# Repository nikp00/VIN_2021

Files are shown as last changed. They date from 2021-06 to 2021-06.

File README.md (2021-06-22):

# Končni projekt pri predmetu VIN 2020/21

Avtor: Nik Prinčič

Mentor: viš. pred. dr. Robert Rozman

### Kazalo

-   [Ideja delovanja](#ideja-delovanja)
-   [Razvojno okolje](#razvojno-okolje)
-   [Delovanje MPU6050](#delovanje-mpu6050)
-   [Delovanje Flex senzorja](#delovanje-flex-senzorja)
-   [Delovanje OLED zaslona (SSD1306)](#delovanje-oled-zaslona--ssd1306-)
-   [Generiranje PPM/CPPM signala](#generiranje-ppm-cppm-signala)
-   [Vezalna shema](#vezalna-shema)
-   [Problemi na katere sem naletel](#problemi-na-katere-sem-naletel)
-   [Zaključek](#zaklju-ek)

## Ideja delovanja

Nadziranje FPV drona z nagibanjem roke (roll, pitch, yaw) ter stiskanjem pesti (throttle). Za zaznavanje nagiba roke sem uporabil MPU6050 (6 DoF IMU), ki ima vgrajen DMP (digital motion processing) enoto, ki prepreči, da bi vrednosti, ki ju izmerita pospeškomer in žiroskop skozi čas začele odstopati zaradi pojava imenovanega "sensor drift". Za nadzor plina (throttle) pa sem uporabil flex senzor v kombinaciji z delilnikom napetosti. Flex senzor v delilniku napetosti opravlja nalogo variabilnega upora R1 (razpon upornosti od 30K do 110K), za upor R2 pa sem izbral upornost 68K. Za vizualizacijo pozicije vsakega od 4 kanalov (stick position) pa sem uporabil OLED zaslon. Vse skupaj pa nadzira Arduino Nano, ki tudi generira CPPM signal ki ga potem preko 3,5mm konektorja pošilja v oddajnik, ki komunicira z dronom.

Da bi vse navedene komponete lahko montiral na roko sem s pomočjo programa za 3D modeliranje in 3D tiskalnika izdelal nekaj nosilcev. Vsi nosilci so izdelani z delno fleksibilnega materiala TPU, da sel lažje prilagodijo obliki roke. Za napajanje pa sem uporabil 18650 Li-Ion celico, ki je preko BMS modula povezana na DC-DC boost module, ki napetost dvigne na 5V.

<p align="center">
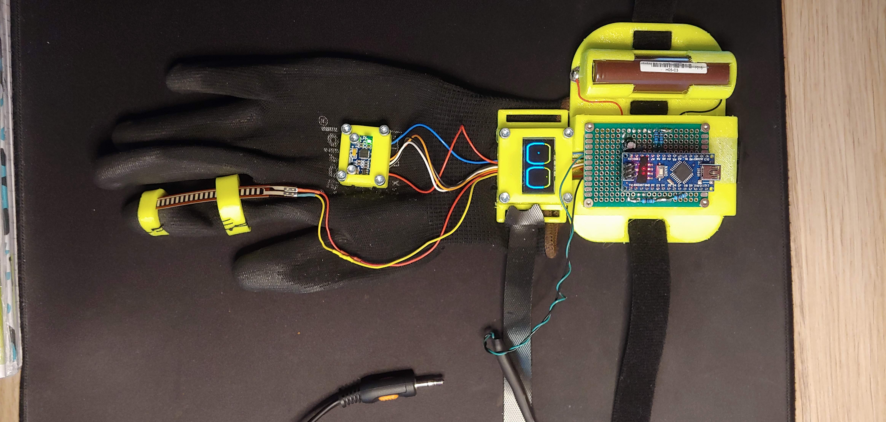
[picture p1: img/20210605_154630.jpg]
 
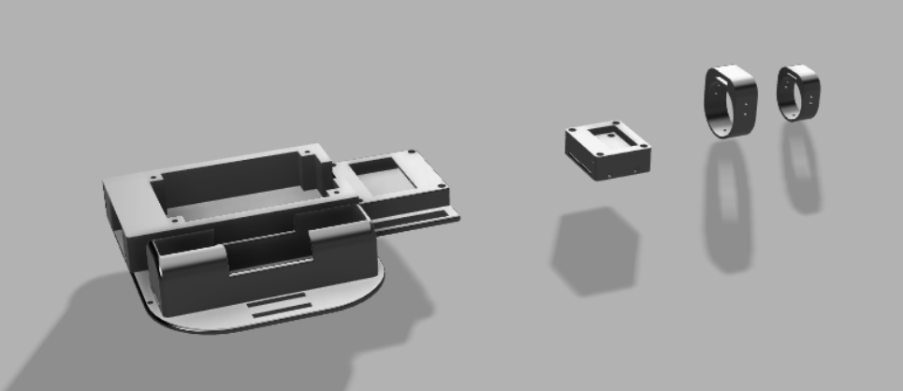
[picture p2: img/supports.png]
  
</p>

## Razvojno okolje

Za razvojno okolje sem si izbral [Platform IO](https://platformio.org/), ki deluje kot vtičnik (plugin) za Microsoft VS Code in ponuja precej več funkcionalnosti od klasičnega Arduino IDE okolja.

<p align="center">
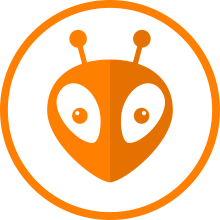
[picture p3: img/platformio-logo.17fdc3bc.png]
 
</p>

## Delovanje MPU6050

MPU6050 uporabljam v načinu, ki izkorišča DMP enoto, zato je poleg I2C povezave potrebna še povezava na prekinitveno nožico Arduina. Ko DMP enota sprocesira pordatke sproži prekinitev, ki Arduino opozori da so podatki pripravljeni za branje. Za interkcijo z MPU6050 sem uporabil knjižnico [Simple_MPU6050](https://github.com/ZHomeSlice/Simple_MPU6050), ki v DMP enoto naloži potrben program (Invensense Embedded MotionDriver 6.12) in olajša vso ostalo konfiguracijo in komunikacijo.

<p align="center">
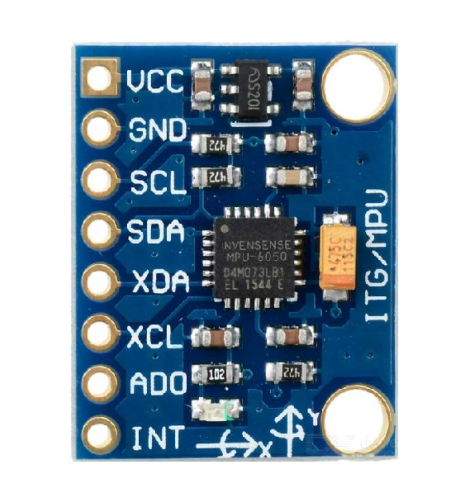
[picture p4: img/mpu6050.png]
 
</p>

## Delovanje Flex senzorja

Flex senzor je preko delilnika napetosti povezan na analogno nožico Arduina. Flex senzor v delilniku napetosti opravlja vlogo variabilnega upora R1, vrednost fiksnega upora R2 pa sem izbral tako, da delilnik napetosti proizvede največjo, še berljivo, razliko v napetosti glede na stanje variabilnega upora R1. Prebrana vrednost se preko ADC pretvornika pretvori v diskretno vrednost, ki se potem z pomočjo funkcije map(), preslika na interval med 1000 in 2000 (min. in max. vrednost servo kanalov). Za kalibracijo senzorja sem najprej moral poiskati max. in min. vrednost, ki jih senzor lahko prebere ko je fiksiran na rokavici. Ker je senzor zelo občutljiv sem uprabil, sem uporabil gladilno funkcijo, ki vzame povprečje zadnjih n meritev. Z testiranjem sem prišel do zaključka da je n=10 dober kompromis med odzivnostjo in stabilnostjo.

<p align="center">
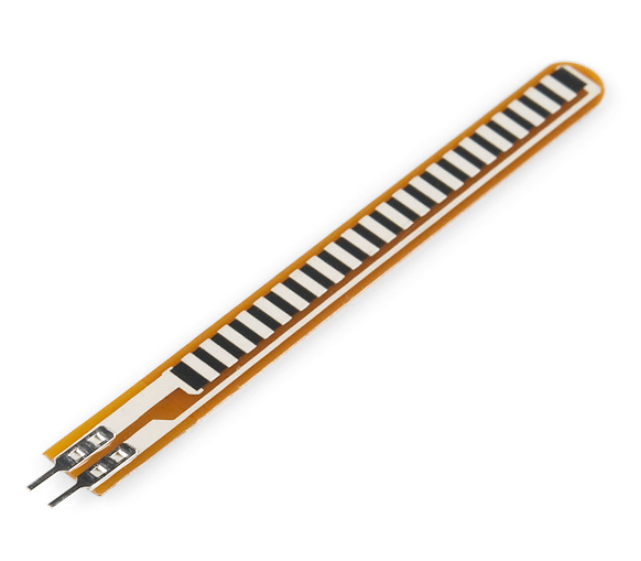
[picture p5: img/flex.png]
 
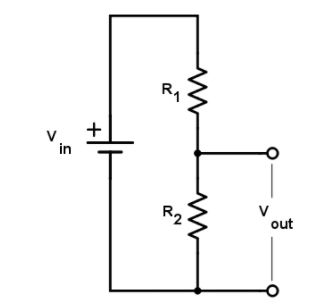
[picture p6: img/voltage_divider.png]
 
</p>

## Delovanje OLED zaslona (SSD1306)

Zalon je na Arduino povezan preko istega I2C vodila kot MPU6050. Na zaslonu so prikazane vrednosti vseh štirih kanalov v obliki "stick position". Za upravljanje zaslona sem uporabil knjižnici Adafruit SSD1306 in Adafruit GFX Library. Zaslon se osveži vsakih 100ms, za tako hitrost osveževanja sem se odločil zato ker je dober kompromis med "tekočim" delovanjem zaslona in obremenitvijo I2C vodila.

<p align="center">
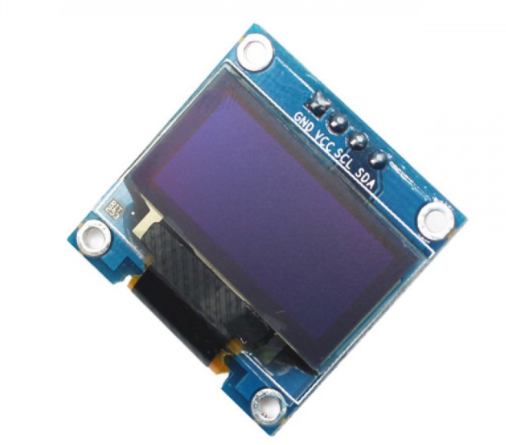
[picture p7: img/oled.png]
 
</p>

## Generiranje PPM/CPPM signala

(Combined) Pulse Position Modulation je vrsta signala, ki se uporablja v večini RC modelov, dronov, letal,... . Poznamo več različni standardov CPPM signalov, pri tem projektu sem uporabil različico, ki podpira do 12 ločenih kanalov, dolžina okvirja je 22,5 ms, dolžina pulza (high state) pa je 0,3 ms, dolžina nizkega stanja (low state) pa je vbrednost_kanala - 0.3ms. Vrednosti kanalov pa so od 1000 do 2000.
Za generiranje signala sem uporabil časovnik, ki šteje z frekvenco 2 MHz (1/(2\*10^6) = 0.5 μs). Časovnik se tudi postavi v CTC način delovanja, ter nastavi se tudi prekinitveni vektor.

Psevdokoda funkcije, ki se izvede ob prekinitvi, ki jo sproži časovnik:

```
state = true
cur_chan_numb = 0
calc_rest = 0
CPPM_MODULATION = HIGH
PULSE_LENGTH = 300
FRAME_LENGTH = 22500
CHANNEL_NUMBER = 12
ppm [CHANNEL_NUMBER]

fun tim_interupt():
    TCNT1 = 0
    if state:
        digital_write(OUT_PIN, HIGH)
        OCR1A = PULSE_LENGTH * 2
        state = false
    else:
        digital_write(OUT_PIN, !CPPM_MODULATION)
        state = true
        if cur_chan_numb >= CHANNEL_NUMBER:
            cur_chan_numb = 0
            calc_rest = calc_rest + PULSE_LENGTH
            OCR1A = (FRAME_LENGTH - calc_rest) * 2
            calc_rest = 0
        else:
            OCR1A = (ppm[cur_chan_numb] - PULSE_LENGTH) * 2
            calc_rest = calc_rest + ppm[cur_chan_numb]
            cur_chan_numb = cur_chan_numb + 1
```

## Vezalna shema

<p align="center">
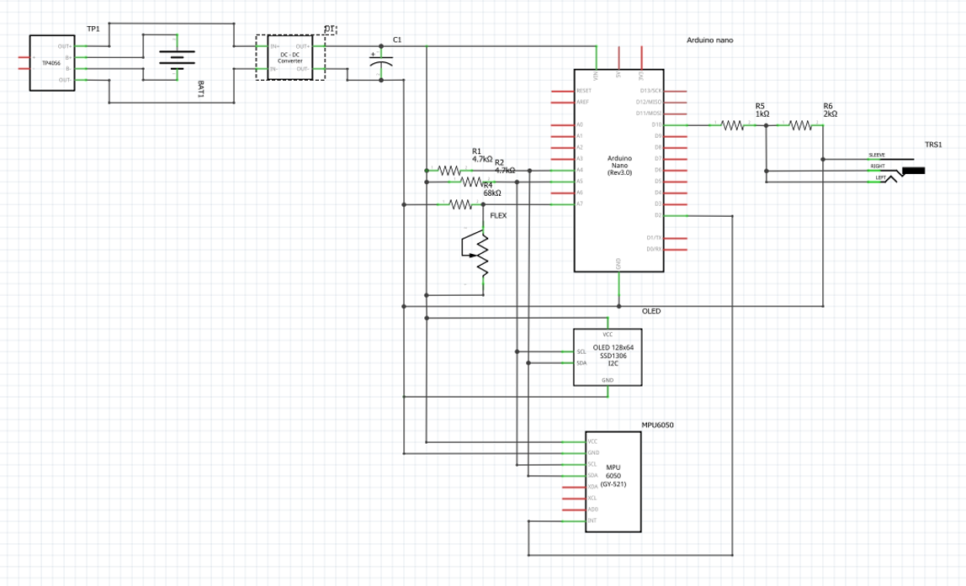
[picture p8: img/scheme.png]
 
</p>

## Problemi na katere sem naletel

-   Pomankanje flash pomnilnika, zato sem iz knjižnic odstranil večino neuporabljenih funkcijonalnosti.
-   Nezanesljiav I2C komunikacija v končnem vezju. I2C komunikacija je na breadboardu delovala normalno smao z built-in pull up upori, ki jih ima Arduino Nano, v končnem vezju pa je prihajalo do napak, zato sem na SDA in SLC linije dodal dodatna 4.7K pull up upora, ki sta rešila problem.

## Zaključek

Idejo za projekt sem imel že nekaj časa, a si nikoli nisem vezl časa, da bi ga realiziral, zato sem izkoristil priložnost in ga realiziral v sklopu predmeta VIN. Med izdelavo sem se naučil kar nekaj novih stvari, na katere med samim načrtovanjem nisem niti preveč pomislil. Končni izdelek je dejansko lahko uporaben za pilotiranje FPV drona, a je sprva občutek zelo čuden, s časom pa pa postane malo bolj podoben občutku pilotiranja z klasičnima joystickoma.

Posnetek delovanja: https://www.youtube.com/watch?v=oFNRZHOGsho

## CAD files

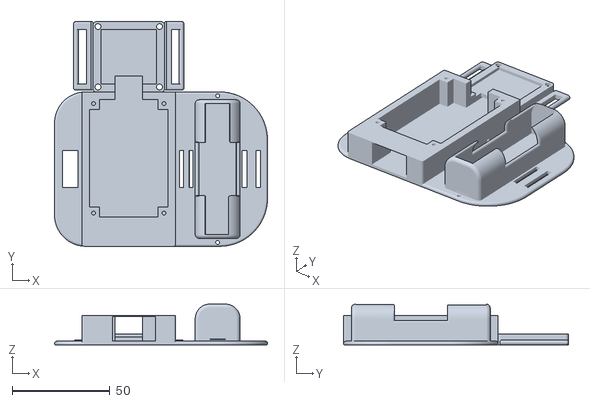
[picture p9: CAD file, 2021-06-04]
STL/main_board_bottom.stl
109.0 x 114.9 x 20.9

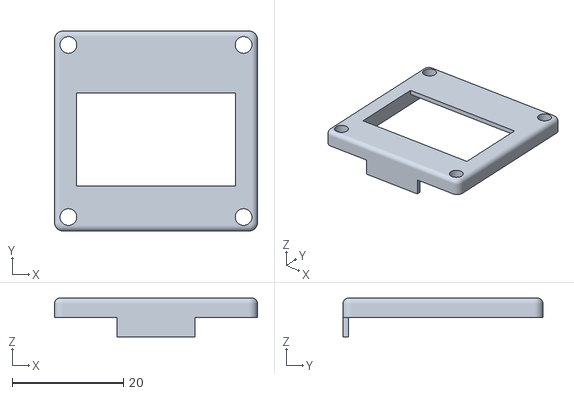
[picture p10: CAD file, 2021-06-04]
STL/OLED_top.stl
36.5 x 35.9 x 7.00

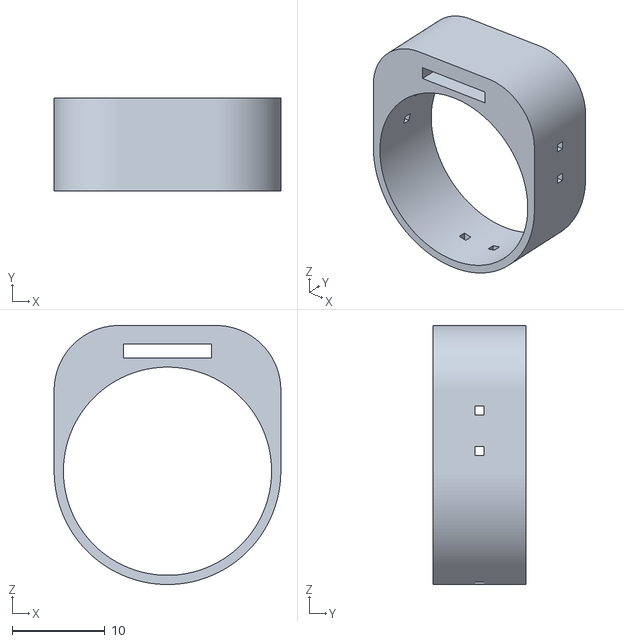
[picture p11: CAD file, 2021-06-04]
STL/finger_upper.stl
24.5 x 10.0 x 28.0

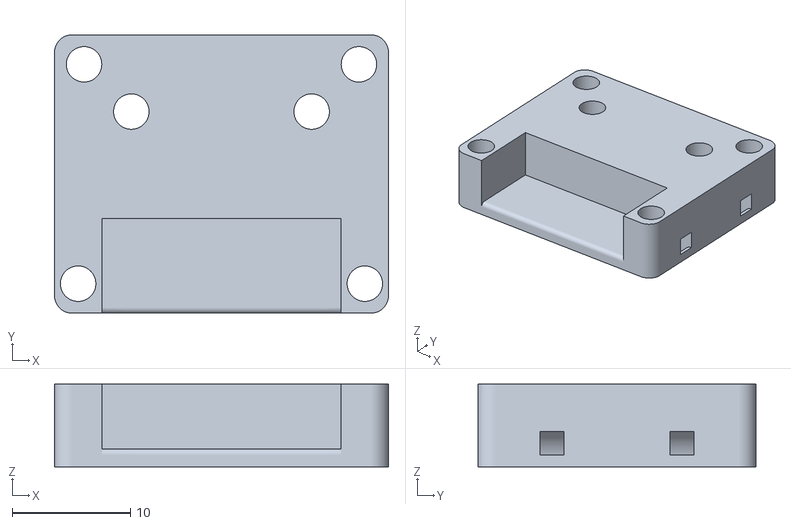
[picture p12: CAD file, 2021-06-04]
STL/MPU_bottom.stl
28.3 x 23.6 x 7.00

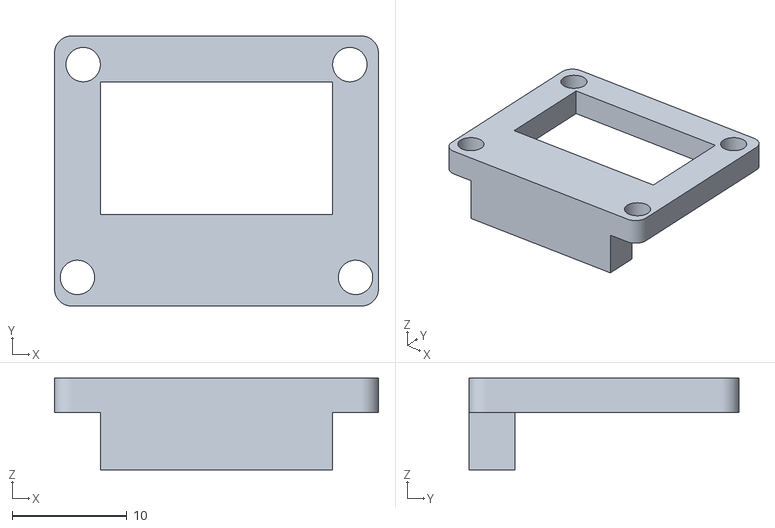
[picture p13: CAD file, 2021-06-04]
STL/MPU_top.stl
28.3 x 23.6 x 8.00

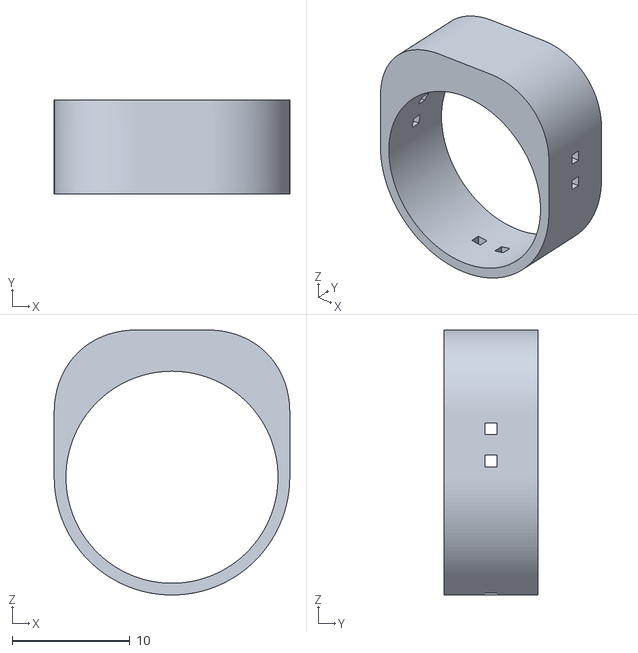
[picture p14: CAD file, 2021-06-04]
STL/finger_lower.stl
20.0 x 8.00 x 22.5

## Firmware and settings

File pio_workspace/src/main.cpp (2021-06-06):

#include <Arduino.h>
#include <Wire.h>
#include <Adafruit_I2CDevice.h>
#include <Adafruit_GFX.h>
#include <Adafruit_SSD1306.h>

#include <I2Cdev.h>
#include <Simple_MPU6050.h>

// OLED screen
#define SCREEN_WIDTH 128    // OLED display width, in pixels
#define SCREEN_HEIGHT 32    // OLED display height, in pixels
#define OLED_RESET 4        // Reset pin # (or -1 if sharing Arduino reset pin)
#define SCREEN_ADDRESS 0x3C ///< See datasheet for Address; 0x3D for 128x64, 0x3C for 128x32

Adafruit_SSD1306 display(SCREEN_WIDTH, SCREEN_HEIGHT, &Wire, OLED_RESET, 400000U, 400000U);

// MPU6050
Simple_MPU6050 mpu;
ENABLE_MPU_OVERFLOW_PROTECTION();
#define spamtimer(t) for (static uint32_t SpamTimer; (uint32_t)(millis() - SpamTimer) >= (t); SpamTimer = millis()) // (BLACK BOX) Ya, don't complain that I used "for(;;){}" instead of "if(){}" for my Blink Without Delay Timer macro. It works nicely!!!
#define OFFSETS 172, 277, 2283, 72, -33, 44
#define MPU6050_ADDRESS_AD0_LOW 0x68  // address pin low (GND), default for InvenSense evaluation board
#define MPU6050_ADDRESS_AD0_HIGH 0x69 // address pin high (VCC)
#define MPU6050_DEFAULT_ADDRESS MPU6050_ADDRESS_AD0_LOW
Quaternion q;
VectorFloat gravity;
float ypr[3];
float xyz[3];

// CPPM
#define CHANNEL_NUMBER 12          //set the number of chanels
#define CHANNEL_DEFAULT_VALUE 1500 //set the default servo value
#define CHANNEL_MIN_VALUE 1000     //set the min servo value
#define CHANNEL_MAX_VALUE 2000     //set the max servo value
#define FRAME_LENGTH 22500         //set the PPM frame length in microseconds (1ms = 1000µs)
#define PULSE_LENGTH 300           //set the pulse length
#define CPPM_MODULATION 1          //set polarity of the pulses: 1 is positive, 0 is negative
#define CPPM_PIN 10                //set PPM signal output pin on the arduino
#define ROLL_CHANNEL 0
#define THROTTLE_CHANNEL 1
#define YAW_CHANNEL 2
#define PITCH_CHANNEL 3

int ppm[CHANNEL_NUMBER];

// Flex sensor
#define FLEX_SENSOR_PIN 21 // A7
#define FLEX_MAX_VALUE 800
#define FLEX_MIN_VALUE 300
#define N_SAMPLES 10

int flex_readings[N_SAMPLES];
uint8_t flex_reading_index = 0;

// Debuging LED
#define LED_PIN 7
bool ledState = false;

ISR(TIMER1_COMPA_vect)
{
    static boolean state = true;

    TCNT1 = 0;

    if (state)
    {
        digitalWrite(CPPM_PIN, CPPM_MODULATION);
        OCR1A = PULSE_LENGTH * 2;
        state = false;
    }
    else
    {
        static byte cur_chan_numb;
        static unsigned int calc_rest;

        digitalWrite(CPPM_PIN, !CPPM_MODULATION);
        state = true;

        if (cur_chan_numb >= CHANNEL_NUMBER)
        {
            cur_chan_numb = 0;
            calc_rest = calc_rest + PULSE_LENGTH; //
            OCR1A = (FRAME_LENGTH - calc_rest) * 2;
            calc_rest = 0;
        }
        else
        {
            OCR1A = (ppm[cur_chan_numb] - PULSE_LENGTH) * 2;
            calc_rest = calc_rest + ppm[cur_chan_numb];
            cur_chan_numb++;
        }
    }
}

void drawRollPitchYawThrottle(int roll, int pitch, int yaw, int throttle)
{
    roll = map(roll, 2000, 1000, 0, 59);
    pitch = map(pitch, 1000, 2000, 0, 32);
    yaw = map(yaw, 2000, 1000, 69, 128);
    throttle = map(throttle, 1000, 2000, 0, 32);
    display.clearDisplay();
    display.drawRoundRect(0, 0, 59, 32, 12, SSD1306_WHITE);
    display.drawRoundRect(69, 0, 59, 32, 12, SSD1306_WHITE);

    // Left stick
    display.drawPixel(yaw, throttle, SSD1306_WHITE);
    // Right stick
    display.drawPixel(roll, pitch, SSD1306_WHITE);
    display.display();
}

void initDisplay()
{
    // SSD1306_SWITCHCAPVCC = generate display voltage from 3.3V internally
    if (!display.begin(SSD1306_SWITCHCAPVCC, SCREEN_ADDRESS))
    {
        Serial.println(F("SSD1306 allocation failed"));
    }

    display.display();
    delay(2000); // Pause for 2 seconds
    display.clearDisplay();
}

void readMPU(int16_t *gyro, int16_t *accel, int32_t *quat, uint32_t *timestamp)
{
    mpu.GetQuaternion(&q, quat);
    mpu.GetGravity(&gravity, &q);
    mpu.GetYawPitchRoll(ypr, &q, &gravity);

    uint16_t yaw = (uint16_t)map(ypr[0] * 180 / M_PI, -90, 90, CHANNEL_MIN_VALUE, CHANNEL_MAX_VALUE);
    uint16_t pitch = (uint16_t)map(ypr[1] * 180 / M_PI, -90, 90, CHANNEL_MAX_VALUE, CHANNEL_MIN_VALUE);
    uint16_t roll = (uint16_t)map(ypr[2] * 180 / M_PI, -90, 90, CHANNEL_MIN_VALUE, CHANNEL_MAX_VALUE);

    ppm[ROLL_CHANNEL] = roll;
    ppm[YAW_CHANNEL] = yaw;
    ppm[PITCH_CHANNEL] = pitch;
}

void initMPU()
{
    Wire.begin();
    Wire.setClock(400000);
    mpu.SetAddress(MPU6050_DEFAULT_ADDRESS).load_DMP_Image(OFFSETS);
    mpu.on_FIFO(readMPU);
}

void initCPPM()
{
    //initiallize default ppm values
    for (int i = 0; i < CHANNEL_NUMBER; i++)
    {
        ppm[i] = CHANNEL_DEFAULT_VALUE;
    }

    pinMode(CPPM_PIN, OUTPUT);
    digitalWrite(CPPM_PIN, !CPPM_MODULATION); //set the PPM signal pin to the default state (off)

    cli();
    TCCR1A = 0; // set entire TCCR1 register to 0
    TCCR1B = 0;

    OCR1A = 100;
    TCCR1B |= (1 << WGM12);  // turn on CTC mode
    TCCR1B |= (1 << CS11);   // 8 prescaler: 0,5 microseconds at 16mhz
    TIMSK1 |= (1 << OCIE1A); // enable timer compare interrupt
    sei();
}

void initFlexSensor()
{
    pinMode(FLEX_SENSOR_PIN, INPUT);
    analogRead(FLEX_SENSOR_PIN);
}

void readFlexSensor()
{
    float raw = analogRead(FLEX_SENSOR_PIN);
    flex_readings[flex_reading_index] = raw;
    flex_reading_index = (flex_reading_index + 1) % N_SAMPLES;

    Serial.println(raw);

    int avg = 0;
    for (int i = 0; i < N_SAMPLES; i++)
    {
        avg += flex_readings[i];
    }

    int throttle = map(avg / N_SAMPLES, FLEX_MIN_VALUE, FLEX_MAX_VALUE, CHANNEL_MAX_VALUE, CHANNEL_MIN_VALUE);
    ppm[THROTTLE_CHANNEL] = throttle;
}

void printChannels()
{
    Serial.print("YAW:\t");
    Serial.print(ppm[YAW_CHANNEL]);
    Serial.print("\t");
    Serial.print("PITCH:\t");
    Serial.print("\t");
    Serial.print(ppm[PITCH_CHANNEL]);
    Serial.print("\t");
    Serial.print("ROLL:\t");
    Serial.print(ppm[ROLL_CHANNEL]);
    Serial.print("\t");
    Serial.print("THROTTLE:\t");
    Serial.print(ppm[THROTTLE_CHANNEL]);
    Serial.print("\t");
    Serial.print("time::\t");
    Serial.println(millis());
}

void setup()
{
    pinMode(LED_PIN, OUTPUT);
    digitalWrite(LED_PIN, HIGH);

    Serial.begin(115200);
    initCPPM();
    initMPU();
    initFlexSensor();
    initDisplay();
}

void loop()
{
    mpu.dmp_read_fifo();

    readFlexSensor();

    digitalWrite(LED_PIN, ledState);
    ledState = !ledState;

    static long timer_display = millis();
    if ((long)(millis() - timer_display) >= 100)
    {
        timer_display = millis();
        drawRollPitchYawThrottle(ppm[ROLL_CHANNEL], ppm[PITCH_CHANNEL], ppm[YAW_CHANNEL], ppm[THROTTLE_CHANNEL]);
    }

    static long timer_serial = millis();
    if ((long)(millis() - timer_serial) >= 1000)
    {
        timer_serial = millis();
        printChannels();
    }
}

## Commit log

2021-06-06 added toc
    [18650.stl, Board_bottom.stl, MPU_bottom_v1.stl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]
2021-06-06 Fixed STLs
    [18650.stl, Board_bottom.stl, MPU_bottom_v1.stl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]
